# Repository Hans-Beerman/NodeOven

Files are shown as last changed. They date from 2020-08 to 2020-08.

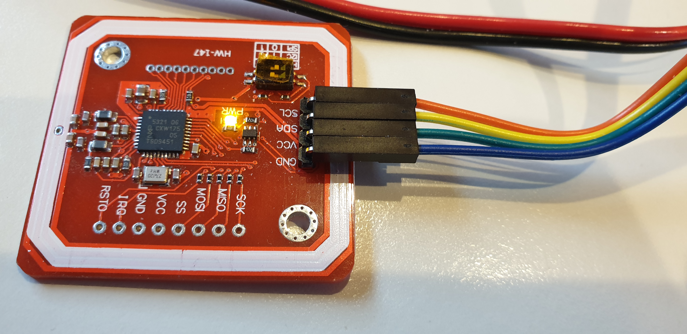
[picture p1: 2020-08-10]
Photos/20200808_105141.jpg

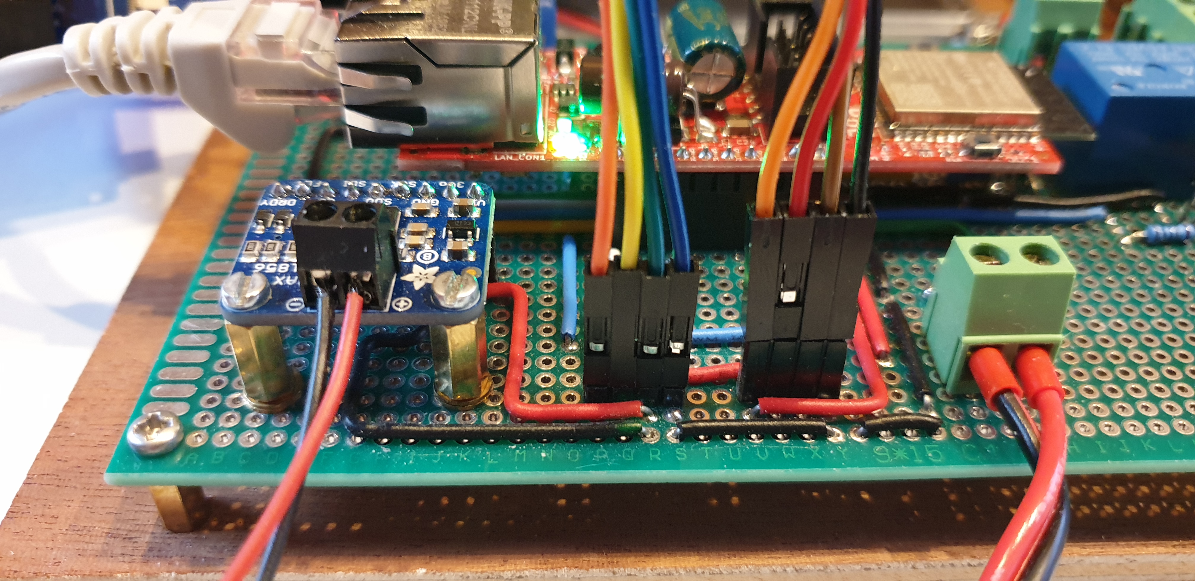
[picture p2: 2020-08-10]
Photos/20200808_105214.jpg

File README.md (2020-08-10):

**NodeOven**

NodeOven is a node, used at the MakerSpace Leiden, to control a Ceramic oven. This repository has the following subdirs:

- **Drawings:**

Schematic of the wiring between the different modules used

- **KiCad\_files:**

The design of the PCB for the Node/Controller. De PCB in this design is not meant to be used for a real PCB. It is used as guideline for a handmade PCB

- **Photos:**

Some photos of the Node made.

- **PlatformIO\_Files:**

The source code for the Node and the display used. For the development of this software PlatformIO is used, an Extension on Visual Studio Code.

For measuring the oven temperature different types of thermocouples can be used. The configuration of the correct one is done in:

/PlatformIO\_Files/NodeOven/platformio.ini

See for possible types to be used, the comment in this file for THERMOCOUPLE\_TYPE=

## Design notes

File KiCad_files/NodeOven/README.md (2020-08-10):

**NodeOven MakerSpace Leiden**

The NodeOven is used to control the ceramic oven of the MakerSpace in Leiden

This repository contains the schematic drawings, made in KiCad for this node.

The PCB in this design is not meant to be used for a real printed circuit board, but is added to be used as a guideline for making the print by hand on a prefab PCB for experimental use.

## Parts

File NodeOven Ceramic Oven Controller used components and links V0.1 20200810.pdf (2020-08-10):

RFID NFC Kit PN532 met S50 Kaart en S50 Key Tag: https://www.tinytronics.nl/shop/nl/communicatie/rfid/rfid-nfc-kit-pn532-met-s50-kaart-en-s50-keytag
https://github.com/elechouse/PN532http://www.elechouse.com/elechouse/index.php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
Of:
http://www.elechouse.com/elechouse/index.php?main_page=product_info&cPath=90_93&products_id=2242
Of:
https://www.elechouse.com/elechouse/index.php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

Adafruit Universele Thermokoppel Versterker MAX31856 Breakout: https://www.kiwi-electronics.nl/adafruit-universal-thermocouple-amplifier-max31856-breakouthttps://learn.adafruit.com/adafruit-max31856-thermocouple-amplifier/overvi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
https://github.com/adafruit/Adafruit_MAX31856

Solid state relais:
https://www.huimultd.com/MOTOR_SPEED_OR_DIRECTION_CONTROL_MODULE/MGR-3-M4825/

Wemos 2.4 inch TFT Shield voor D1 Mini - Met Touchscreen: https://www.tinytronics.nl/shop/nl/display/tft/wemos-2.4-inch-tft-shield-voor-d1-mini-mettouchscreen
https://docs.wemos.cc/en/latest/d1_mini_shiled/tft_2_4.htmlhttps://docs.wemos.cc/en/latest/_static/files/sch_tft2.4_v1.0.0.pdfhttps://docs.wemos.cc/en/latest/_static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 hield

RobotDyn D1 Mini Pro - ESP8266 - 4MB - CP2104: https://www.tinytronics.nl/shop/nl/arduino/wemos/robotdyn-d1-mini-pro-esp8266-4mb-cp2104https://robotdyn.com/wifi-d1-mini-esp8266-dev-board-usb-cp2104.htmlhttps://ro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
https://robotdyn.com/pub/media/images/pdf.png

ESP32-PoE:
https://www.olimex.com/Products/IoT/ESP32/ESP32-POE/open-source-hardwarehttps://github.com/OLIMEX/ESP32-POE/blob/master/HARDWARE/ESP32-PoE-hardware-revision-D/ESP32-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
https://www.olimex.com/Products/IoT/ESP32/ESP32-POE/resources/ESP32-POE-GPIO.png

Webserver:
https://lastminuteengineers.com/creating-esp32-web-server-arduino-ide/https://randomnerdtutorials.com/esp32-esp8266-input-data-html-form/https://circuits4you.com/201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

Ovenregeling:
https://create.arduino.cc/projecthub/arduinokiln/electric-kiln-controller-f5c633\https://art-et-ceramique.fr/regulateur-page-principalehttps://playground.arduino.cc/Code/PIDLibrary/

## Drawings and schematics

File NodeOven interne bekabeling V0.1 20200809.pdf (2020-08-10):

## SSR

20

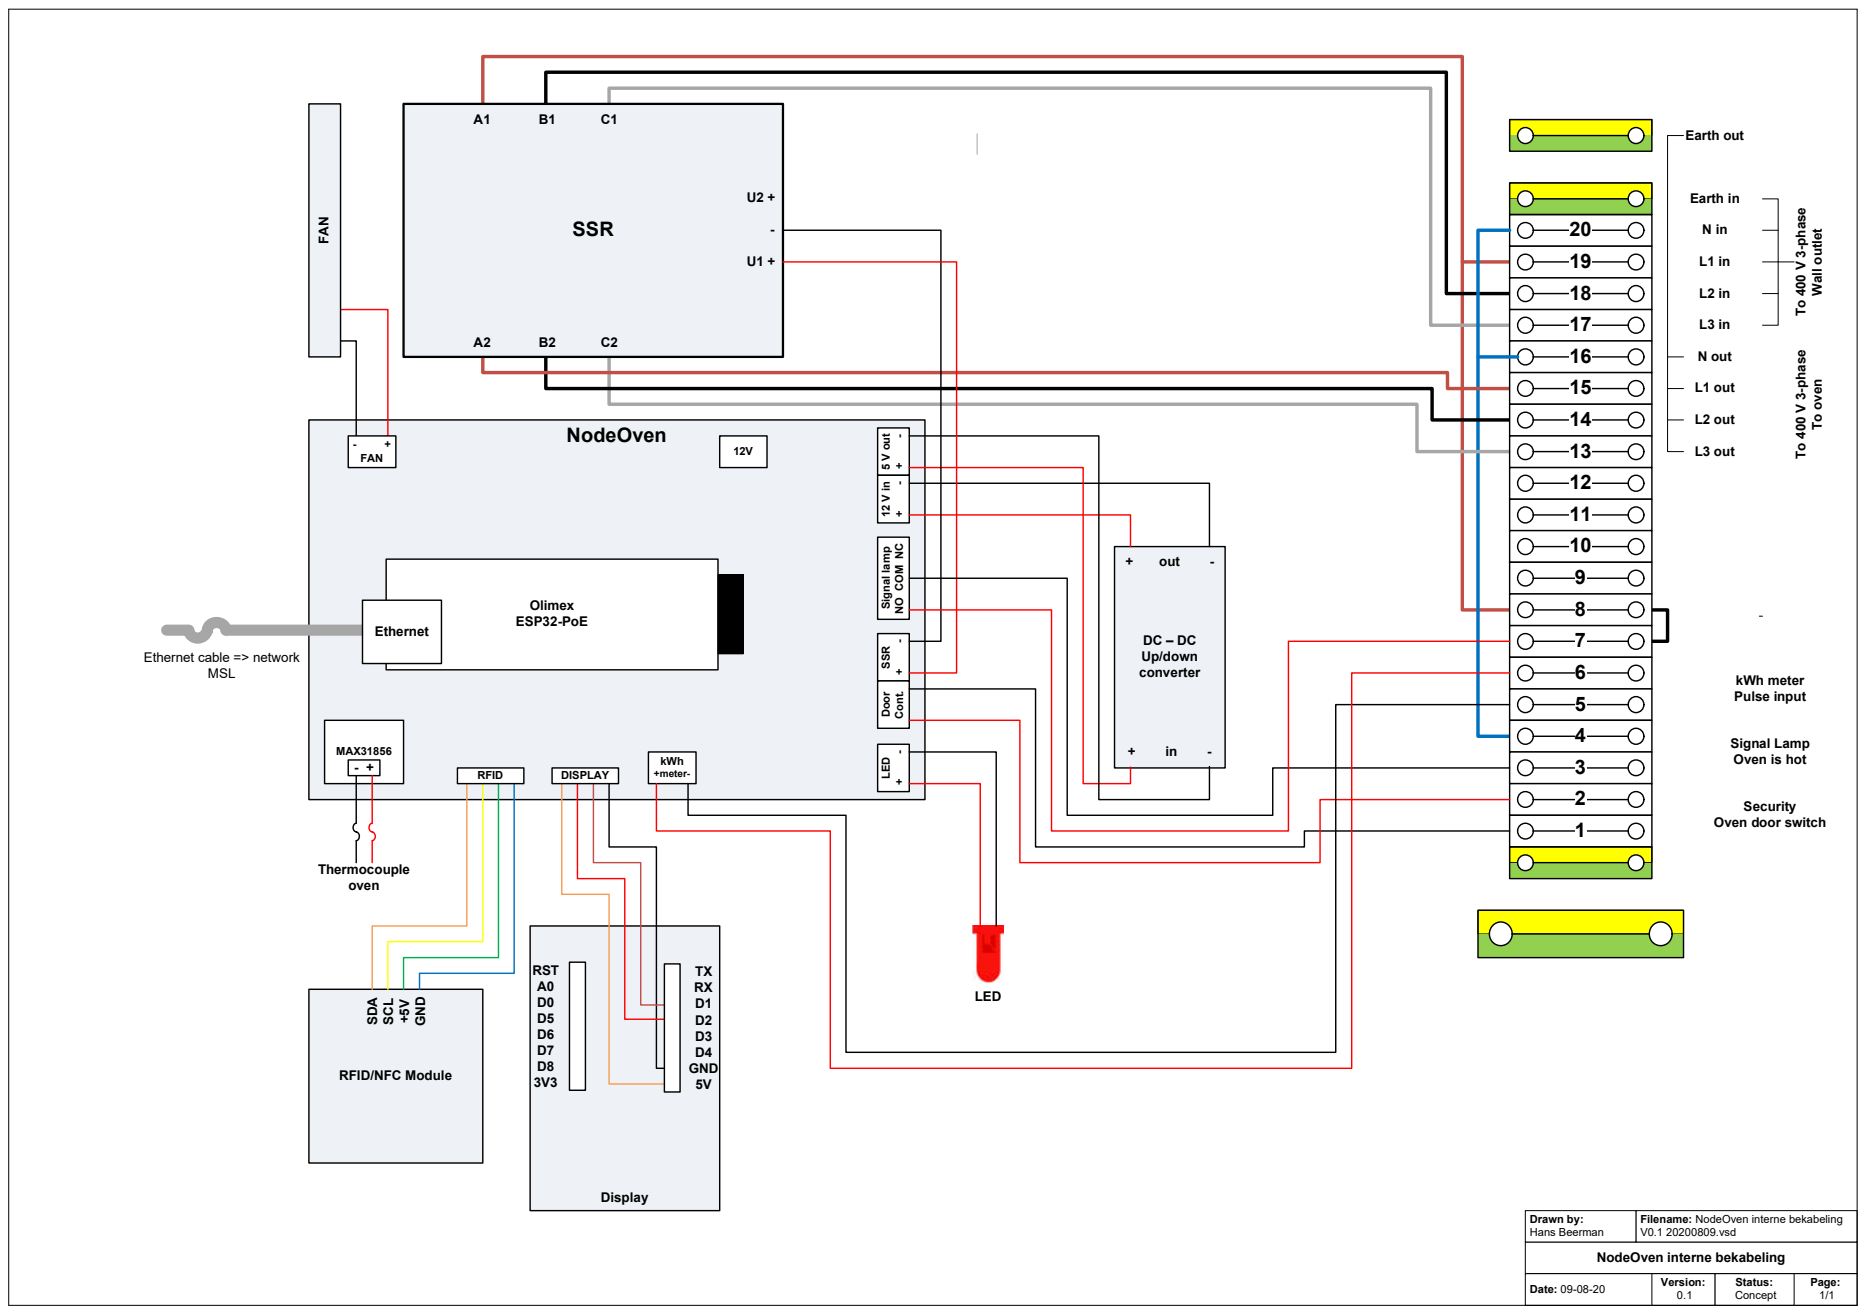
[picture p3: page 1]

Earth in

To 400 V 3-phase
N out L1 out L2 out L3 out

Filename: NodeOven interne bekabeling V0.1 20200809.vsd

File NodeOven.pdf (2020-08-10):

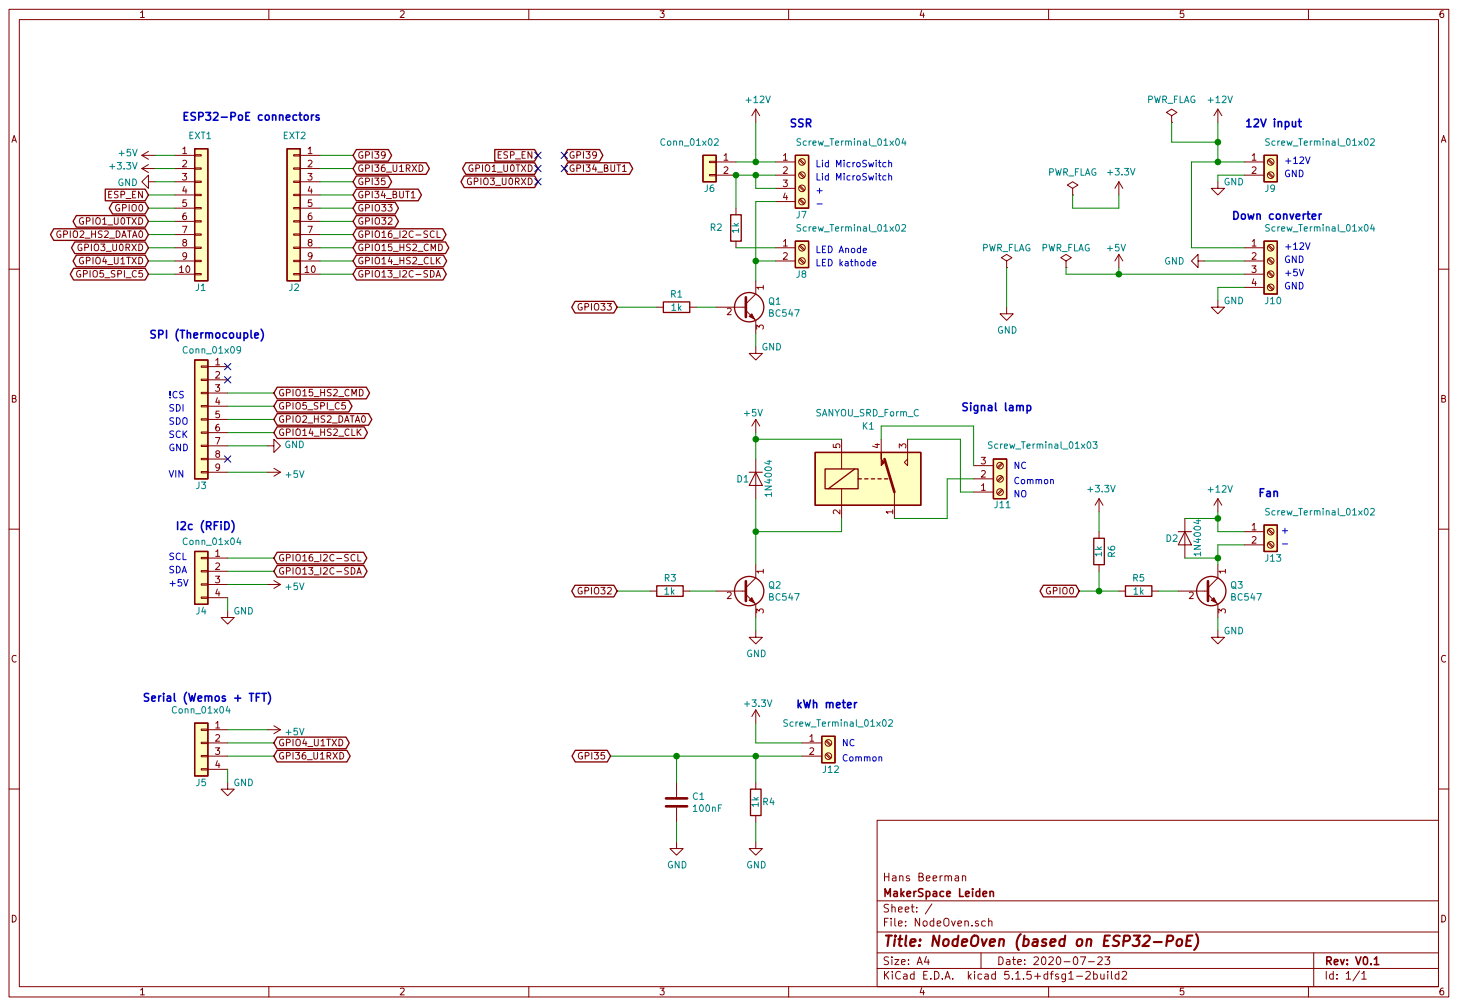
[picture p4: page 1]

Id: 1/1 Title: NodeOven (based on ESP32-PoE) File: NodeOven.sch Sheet: / MakerSpace Leiden Hans Beerman

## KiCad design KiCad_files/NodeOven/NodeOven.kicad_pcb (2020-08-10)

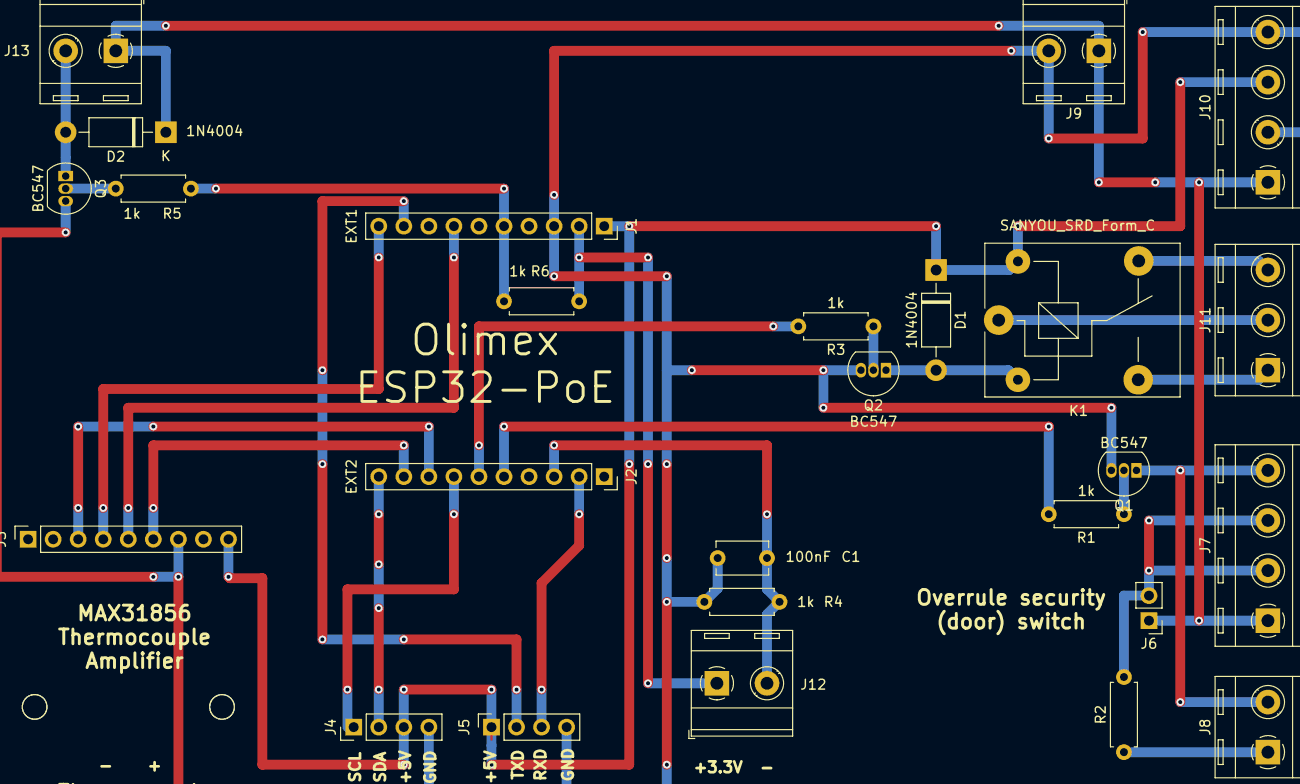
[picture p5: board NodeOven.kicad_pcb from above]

Board: 2 copper layers, 26 parts (0 on the bottom side), 27 nets.

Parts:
C1: 100nF; C_Disc_D5.1mm_W3.2mm_P5.00mm
D1, D2: 1N4004; D_DO-41_SOD81_P10.16mm_Horizontal
J1: EXT1; PinSocket_1x10_P2.54mm_Vertical
J2: EXT2; PinSocket_1x10_P2.54mm_Vertical
J3: Conn_01x09; PinSocket_1x09_P2.54mm_Vertical
J4: Conn_01x04; PinHeader_1x04_P2.54mm_Vertical
J5: Conn_01x04; PinSocket_1x04_P2.54mm_Vertical
J6: Conn_01x02; PinHeader_1x02_P2.54mm_Vertical
J7, J10: Screw_Terminal_01x04; TerminalBlock_RND_205-00289_1x04_P5.08mm_Horizontal
J8, J9, J12, J13: Screw_Terminal_01x02; TerminalBlock_RND_205-00287_1x02_P5.08mm_Horizontal
J11: Screw_Terminal_01x03; TerminalBlock_RND_205-00288_1x03_P5.08mm_Horizontal
K1: SANYOU_SRD_Form_C; Relay_SPDT_SANYOU_SRD_Series_Form_C
Q1, Q2, Q3: BC547; TO-92_Inline
R1, R2, R3, R4, R5, R6: 1k; R_Axial_DIN0207_L6.3mm_D2.5mm_P7.62mm_Horizontal

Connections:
+3V3: J1.2, J12.1, R6.2
+5V: D1.1, J1.1, J3.9, J4.3, J5.1, J10.3, K1.5
+12V: D2.1, J6.1, J7.1, J9.1, J10.1, J13.1
GND: C1.2, J1.3, J3.7, J4.4, J5.4, J9.2, J10.2, J10.4, Q1.3, Q2.3, Q3.3, R4.1
GPI35: C1.1, J2.3, J12.2, R4.2
GPI36_U1RXD: J2.2, J5.3
GPIO0: J1.5, R5.2, R6.1
GPIO2_HS2_DATA0: J1.7, J3.5
GPIO4_U1TXD: J1.9, J5.2
GPIO5_SPI_C5: J1.10, J3.4
GPIO13_I2C-SDA: J2.10, J4.2
GPIO14_HS2_CLK: J2.9, J3.6
GPIO15_HS2_CMD: J2.8, J3.3
GPIO16_I2C-SCL: J2.7, J4.1
GPIO32: J2.6, R3.2
GPIO33: J2.5, R1.2
unnamed: D1.2, K1.2, Q2.1
unnamed: D2.2, J13.2, Q3.1
unnamed: J6.2, J7.2, J7.3, R2.2
unnamed: J7.4, J8.2, Q1.1
unnamed: J8.1, R2.1
unnamed: J11.1, K1.3
unnamed: J11.2, K1.1
unnamed: J11.3, K1.4
unnamed: Q1.2, R1.1
unnamed: Q2.2, R3.1
unnamed: Q3.2, R5.1

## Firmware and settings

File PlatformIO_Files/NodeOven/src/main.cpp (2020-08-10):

/*
      Copyright 2015-2018 Dirk-Willem van Gulik <dirkx@webweaving.org>
      Copyright 2020      Hans Beerman <hans.beerman@xs4all.nl>
                          Stichting Makerspace Leiden, the Netherlands.

   Licensed under the Apache License, Version 2.0 (the "License");
   you may not use this file except in compliance with the License.
   You may obtain a copy of the License at

       http://www.apache.org/licenses/LICENSE-2.0

   Unless required by applicable law or agreed to in writing, software
   distributed under the License is distributed on an "AS IS" BASIS,
   WITHOUT WARRANTIES OR CONDITIONS OF ANY KIND, either express or implied.
   See the License for the specific language governing permissions and
   limitations under the License.
*/

#ifndef ESP32
#error "The MetalNode uses an ESP32 based board (Olimex ESP32-PoE)!"
#endif

// An Olimex ESP32-PoE is used (default is POESP board (Aart board))
#define ESP32_PoE


// for debugging
// see DEBUGIT flag in platformio.ini

// i2C params
#define RFID_SDA_PIN    (13)
#define RFID_SCL_PIN    (16)

#include <Arduino.h>
#include <PowerNodeV11.h>
#include <ACNode.h>
#include <RFID.h>   // NFC version
#include <SIG2.h>
#include <Cache.h>
#include <EEPROM.h>

#include ".passwd.h"
/* If using WiFi instead of a fixed ethernet connection, and/or OTA:

Add Passwd.h to the NodeOven/src directoy containing the following information

#pragma once

#define WIFI_NETWORK "YOUR_SSID"
#define WIFI_PASSWD "YOUR_PASSWD"

#define OTA_PASSWD "YOUR_OTA_PASSWD"
*/

#include "pid.h"


#define MACHINE "nodeoven"

#define SOLID_STATE_RELAIS_PIN  (33)
#define SIGNAL_LAMP_PIN         (32)
#define FAN_PIN                 (0)
#define KWH_METER_PIN           (35)

#define SERIAL_RX_PIN               36
#define SERIAL_TX_PIN               4

#define SERIAL_MAXLINELENGTH        128
#define SERIAL2_BAUDRATE            19200

#define DISPLAY_UPDATE_INTERVAL     1000 // in ms


// See https://mailman.makerspaceleiden.nl/mailman/private/deelnemers/2019-February/019837.html

// Introduced by alex - 2020-01-8

// Clear EEProm + Cache button
// Press BUT1 on Olimex ESP32 PoE module before (re)boot of node
// keep BUT1 pressed for at least 5 s
// After the release of BUT1 node will restart with empty EEProm and empty cache
#define CLEAR_EEPROM_AND_CACHE_BUTTON         (34)
#define CLEAR_EEPROM_AND_CACHE_BUTTON_PRESSED (LOW)
#define MAX_WAIT_TIME_BUTTON_PRESSED          (4000)  // in ms


#ifdef WIFI_NETWORK
ACNode node = ACNode(MACHINE, WIFI_NETWORK, WIFI_PASSWD);
#else
ACNode node = ACNode(MACHINE);
#endif

RFID reader = RFID(false); // don't use tags already stored in cache, to see in the server who has used the oven

MqttLogStream mqttlogStream = MqttLogStream();
TelnetSerialStream telnetSerialStream = TelnetSerialStream();

// Use software SPI: CS, DI, DO, CLK
Adafruit_MAX31856 thermo = Adafruit_MAX31856(15, 5, 2, 14);


#ifdef OTA_PASSWD
OTA ota = OTA(OTA_PASSWD);
#endif

// LED aartLed = LED(SYSTEM_LED);    // defaults to the aartLed - otherwise specify a GPIO.

typedef enum {
  BOOTING, OUTOFORDER,      // device not functional.
  REBOOT,                   // forcefull reboot
  TRANSIENTERROR,           // hopefully goes away level error
  NOCONN,                   // sort of fairly hopless (though we can cache RFIDs!)
  WAITINGFORCARD,           // waiting for card.
  CHECKINGCARD,
  CLEARSTATUS,
  APPROVED,
  REJECTED,
  OVENON,
  OVENOFF,
} machinestates_t;


#define NEVER (0)

struct {
  const char * label;                   // name of this state
  LED::led_state_t ledState;            // flashing pattern for the aartLED. Zie ook https://wiki.makerspaceleiden.nl/mediawiki/index.php/Powernode_1.1.
  time_t maxTimeInMilliSeconds;         // how long we can stay in this state before we timeout.
  machinestates_t failStateOnTimeout;   // what state we transition to on timeout.
  unsigned long timeInState;
  unsigned long timeoutTransitions;
  unsigned long autoReportCycle;
} state[OVENOFF + 1] =
{
  { "Booting",                LED::LED_ERROR,                   120 * 1000, REBOOT,         0 },
  { "Out of order",           LED::LED_ERROR,                   120 * 1000, REBOOT,         5 * 60 * 1000 },
  { "Rebooting",              LED::LED_ERROR,                   120 * 1000, REBOOT,         0 },
  { "Transient Error",        LED::LED_ERROR,                     5 * 1000, WAITINGFORCARD, 5 * 60 * 1000 },
  { "No network",             LED::LED_FLASH,                        NEVER, NOCONN,         0 },
  { "Waiting for card",       LED::LED_IDLE,                         NEVER, WAITINGFORCARD, 0 },
  { "Checking card",          LED::LED_PENDING,                   5 * 1000, WAITINGFORCARD, 0 },
  { "Clear status",           LED::LED_PENDING,                      NEVER, WAITINGFORCARD, 0 },
  { "Approved card",          LED::LED_PENDING,                  60 * 1000, CLEARSTATUS,    0 },
  { "Rejected",               LED::LED_ERROR,                     5 * 1000, CLEARSTATUS,    0 },
  { "Device(s) switched on",  LED::LED_ON,  MAX_OVEN_ON_TIME * 3600 * 1000, OVENOFF,        0 },
  { "Switch oven off",        LED::LED_ON,                           NEVER, WAITINGFORCARD, 0 },
};

enum messID {
  e_Beat = 1,
  e_Prev,
  e_Next,
  e_On,
  e_Off
};

enum displayMessageID {
	e_BeatAnswer = 1,
	e_CurrentSchedule,
	e_ScheduleName,
	e_CurrentSegment,
	e_Mode,
	e_Goal,
	e_TimeLeft,
	e_Empty,
	e_IsOn,
	e_IsOff,
	e_Fault,
	e_Solved,
	e_OvenTemp,
	e_Authenticate,
	e_ClearMessage,
	e_Status
};

unsigned long laststatechange = 0, lastReport = 0;
static machinestates_t laststate = OUTOFORDER;
machinestates_t machinestate = BOOTING;

// to handle onconnect only once (only after reboot)
static bool firstOnConnectTime = true;

PIDController * _OvenController;

char reportStr[128];

ESP32WebServer myWebServer(80);

unsigned long wattPulses = 0;
bool kWhPinIsHigh = false;
unsigned long startPinChange = 0;

char messageReceived[SERIAL_MAXLINELENGTH];

bool firstTimeSerialBeatReceived = true;

char tmpStr[255];

unsigned long displayUpdateStartTime = 0;

int prevSchedule = -1;
int prevSegment = -1;
bool clearMessageSent = false;

bool thermoCoupleFault = false;

void updateDisplayTop() {
  String tmpStr;
  char resultStr[SERIAL_MAXLINELENGTH];

  if (prevSchedule != _OvenController->getSelectedSchedule()) {
    prevSchedule = _OvenController->getSelectedSchedule();
    prevSegment = -1;
    sprintf(resultStr, "%d:%d", e_CurrentSchedule, _OvenController->getSelectedSchedule());
    Serial2.println(resultStr);
    tmpStr = _OvenController->getScheduleName();
    sprintf(resultStr, "%d:%s", e_ScheduleName, tmpStr.c_str());
    Serial2.println(resultStr);
    if (_OvenController->getScheduleIsEmpty()) {
      sprintf(resultStr, "%d", e_Empty);
      Serial2.println(resultStr);
    } else {
      sprintf(resultStr, "%d", e_ClearMessage);
      Serial2.println(resultStr);
    }
  }
}

void updateDisplayBottom() {
  String tmpStr;
  char resultStr[SERIAL_MAXLINELENGTH];

  if ((machinestate == OVENON) || _OvenController->ovenIsSwitchedOn()) {
    if (prevSegment != _OvenController->getCurrentSegment()) {
      prevSegment = _OvenController->getCurrentSegment();
      sprintf(resultStr, "%d:%d", e_CurrentSegment, _OvenController->getCurrentSegment());
      Serial2.println(resultStr);
      sprintf(resultStr, "%d:%s", e_Mode, _OvenController->getCurrentMode().c_str());
      Serial2.println(resultStr);
      sprintf(resultStr, "%d:%d", e_Goal, (int)_OvenController->getCurrentGoal());
      Serial2.println(resultStr);
      clearMessageSent = false;
    }
    sprintf(resultStr, "%d:%lu", e_TimeLeft, _OvenController->getTimeLeft());
    Serial2.println(resultStr);
  } else {
    if (!clearMessageSent) {
      sprintf(resultStr, "%d", e_ClearMessage);
      Serial2.println(resultStr);
      clearMessageSent = true;
    }
  }
}

void decodeMessageReceived(int messageID) {
  //String tmpStr;
  char resultStr[SERIAL_MAXLINELENGTH];
 

  switch (messageID) {
  case e_Beat:
    // BEAT received, answer with BEAT
    sprintf(resultStr, "%d", e_BeatAnswer);
    Serial2.println(resultStr);
    if (firstTimeSerialBeatReceived) {
      firstTimeSerialBeatReceived = false;
      updateDisplayTop();
    }
    break;

  case e_Prev:
    // Select previous schedule
    // Check if oven is switched off
    if ((machinestate == OVENON) || _OvenController->ovenIsSwitchedOn()) {
      // skip message
    } else {
      _OvenController->selectSchedule(false);
      updateDisplayTop();
    }
    break;

  case e_Next:
    // Select next schedule
    //Check if oven is switched off
    if ((machinestate == OVENON) || _OvenController->ovenIsSwitchedOn()) {
      // skip message
    } else {
      _OvenController->selectSchedule(true);
      updateDisplayTop();
    }
    break;
      
  case e_On:
    // Switch oven on (if needed/possible)
    // Check if oven is already on
    if ((machinestate == OVENON) || _OvenController->ovenIsSwitchedOn()) {
      // skip request, oven is already on
      return;
    }
 
    // Check if schedule is empty
    if (_OvenController->getScheduleIsEmpty()) {
      sprintf(resultStr, "%d", e_Empty);
      Serial2.println(resultStr);
      return;
    }
 
    // Check if user is approved
    if (machinestate != APPROVED) {
      sprintf(resultStr, "%d", e_Authenticate);
      Serial2.println(resultStr);

      return;
    }

    // Switch oven on
    _OvenController->switchOvenOn();
    sprintf(resultStr, "%d", e_IsOn);
    Serial2.println(resultStr);
    sprintf(resultStr, "%d:0", e_Status); // clear status
    Serial2.println(resultStr);
    machinestate = OVENON;
    prevSegment = -1;
    updateDisplayBottom();
    break;

  case e_Off:
    // switch oven off
    _OvenController->switchOvenOff();
    sprintf(resultStr, "%d", e_IsOff);
    Serial2.println(resultStr);
    machinestate = WAITINGFORCARD;
    sprintf(resultStr, "%d:0", e_Status); // clear status
    Serial2.println(resultStr);
    clearMessageSent = false;
    updateDisplayBottom();
    break;
  }
}

void readSerial2()
{
  if (Serial2.available()) {
    //memset(messageReceived, 0, sizeof(messageReceived));

    while (Serial2.available())
    {
      int len = Serial2.readBytesUntil('\n', messageReceived, SERIAL_MAXLINELENGTH - 1);
      messageReceived[len] = 0;
#ifdef DEBUGIT      
      // Serial.printf("Message received: %s\n\r", messageReceived);
#endif      

      int messageId = atoi(messageReceived);
      decodeMessageReceived(messageId);
    }
  }
}

void displayLoop() {
  if ((millis() - displayUpdateStartTime) > DISPLAY_UPDATE_INTERVAL) {
    displayUpdateStartTime = millis();
    if ((machinestate == OVENON) || _OvenController->ovenIsSwitchedOn()) {
      updateDisplayBottom();
    } else {
      updateDisplayTop();
    }
    double currentOvenTemp = _OvenController->getThermoCoupleTemp();
    if ((currentOvenTemp > -300) && !_OvenController->getTempFault()) {
      sprintf(tmpStr, "%d:%d", e_OvenTemp, (int)currentOvenTemp);
      Serial2.println(tmpStr);
      if (thermoCoupleFault) {
        sprintf(tmpStr, "%d", e_Solved);
        Serial2.println(tmpStr);
        thermoCoupleFault = false;
      }
    } else {
      if (_OvenController->getTempFault()) {
        if (!thermoCoupleFault) {
          thermoCoupleFault = true;
          sprintf(tmpStr, "%d", e_Fault);
          Serial2.println(tmpStr);
        }
      }
    }
  }
}

void countkWhPulses() {
  int currentPinValue = 0;
  currentPinValue = digitalRead(KWH_METER_PIN);
  if (( currentPinValue == HIGH) && !kWhPinIsHigh && (millis() - startPinChange) > 50) {
    startPinChange = millis();
    wattPulses++;
    kWhPinIsHigh = true;
  } else {
    if ((currentPinValue == LOW) && kWhPinIsHigh && (millis() - startPinChange) > 50) {
      startPinChange = millis();
      kWhPinIsHigh = false;
    }
  }
}

void checkClearEEPromAndCacheButtonPressed(void) {
  unsigned long ButtonPressedTime;
  unsigned long currentSecs;
  unsigned long prevSecs;
  bool firstTime = true;

  // check CLEAR_EEPROM_AND_CACHE_BUTTON pressed
  pinMode(CLEAR_EEPROM_AND_CACHE_BUTTON, INPUT);
  // check if button is pressed for at least 3 s
  Log.println("Checking if the button is pressed for clearing EEProm and cache");
  ButtonPressedTime = millis();  
  prevSecs = MAX_WAIT_TIME_BUTTON_PRESSED / 1000;
  Log.print(prevSecs);
  Log.print(" s");
  while (digitalRead(CLEAR_EEPROM_AND_CACHE_BUTTON) == CLEAR_EEPROM_AND_CACHE_BUTTON_PRESSED) {
    if ((millis() - ButtonPressedTime) >= MAX_WAIT_TIME_BUTTON_PRESSED) {
      if (firstTime == true) {
        Log.print("\rPlease release button");
        firstTime = false;
      }
    } else {
      currentSecs = (MAX_WAIT_TIME_BUTTON_PRESSED - millis()) / 1000;
      if ((currentSecs != prevSecs) && (currentSecs >= 0)) {
        Log.print("\r");
        Log.print(currentSecs);
        Log.print(" s");
        prevSecs = currentSecs;
      }
    }
  }
  if (millis() - ButtonPressedTime >= MAX_WAIT_TIME_BUTTON_PRESSED) {
    Log.print("\rButton for clearing EEProm and cache was pressed for more than ");
    Log.print(MAX_WAIT_TIME_BUTTON_PRESSED / 1000);
    Log.println(" s, EEProm and Cache will be cleared!");
    // Clear EEPROM
    EEPROM.begin(1024);
    wipe_eeprom();
    Log.println("EEProm cleared!");
    // Clear cache
    prepareCache(true);
    Log.println("Cache cleared!");
    // wait until button is released, than reboot
    while (digitalRead(CLEAR_EEPROM_AND_CACHE_BUTTON) == CLEAR_EEPROM_AND_CACHE_BUTTON_PRESSED) {
      // do nothing here
    }
    Log.println("Node will be restarted");
    // restart node
    ESP.restart();
  } else {
    Log.println("\rButton was not (or not long enough) pressed to clear EEProm and cache");
  }
}


int inputIsHigh = 0;

void handleNotFound() {
  myWebServer.send(404, "text/plain", "404: Not found"); // Send HTTP status 404 (Not Found) when there's no handler for the URI in the request
}


void setup() {
  Serial.begin(115200);
  Serial.println("\n\n\n");
  Serial.println("Booted: " __FILE__ " " __DATE__ " " __TIME__ );

  Serial2.begin(SERIAL2_BAUDRATE, SERIAL_8N1, SERIAL_RX_PIN, SERIAL_TX_PIN);
  Serial2.setRxBufferSize(256);
  Serial2.flush();

  sprintf(tmpStr, "%d:1", e_Status); // Please wait, controller is starting
  Serial2.println(tmpStr);

  pinMode(KWH_METER_PIN, INPUT);

  checkClearEEPromAndCacheButtonPressed();

  _OvenController = new PIDController();
  _OvenController->begin(SOLID_STATE_RELAIS_PIN, FAN_PIN, SIGNAL_LAMP_PIN);

  node.set_mqtt_prefix("ac");
  node.set_master("master");

  node.onConnect([]() {
    Log.println("Connected");
    if (firstOnConnectTime == true) {
      _OvenController->setUserIsApproved(false);
      firstOnConnectTime = false;
      machinestate = WAITINGFORCARD;
    }
  });
  node.onDisconnect([]() {
    Log.println("Disconnected");
//    machinestate = NOCONN;
  });
  node.onError([](acnode_error_t err) {
    Log.printf("Error %d\n", err);
    _OvenController->setUserIsApproved(false);
    machinestate = WAITINGFORCARD;
  });
  node.onApproval([](const char * machine) {
    char resultStr2[SERIAL_MAXLINELENGTH];
    Debug.print("Got approve for machine: ");
    Debug.println(machine);
    if (machinestate == WAITINGFORCARD) {
      _OvenController->setUserIsApproved(true);
      sprintf(resultStr2, "%d:2", e_Status); // User authenticated
      Serial2.println(resultStr2);

      sprintf(resultStr2, "%d", e_ClearMessage);
      Serial2.println(resultStr2);

      machinestate = APPROVED;
      Log.println("User is approved and is now allowed to switch the oven on");
    }
  });
  node.onDenied([](const char * machine) {
    char resultStr3[SERIAL_MAXLINELENGTH];
    Debug.println("Got denied");
    if (machinestate > REJECTED) {
      Debug.println("Denied ingnored, oven is already in use");
    } else {
      machinestate = REJECTED;
      _OvenController->setUserIsApproved(false);
      sprintf(resultStr3, "%d:3", e_Status);  // User denied
      Serial2.println(resultStr3);
    }
  });

  node.set_report_period(20 * 1000);
  node.onReport([](JsonObject  & report) {
    report["state"] = state[machinestate].label;

    if (_OvenController->getAllowPidControllerIsOn()) {
      report["ovencontroller"] = "enabled";
    } else {
      report["ovencontroller"] = "disabled";
    }

    if (_OvenController->getSSRIsOn()) {
      report["Solid State Relais"] = "switched on";
    } else {
      report["Solid State Relais"] = "switched off";
    }

    _OvenController->measureOvenTemps();
    if (_OvenController->getTempFault()) {
      report["Thermocouple"] = "error detected";
    } else {
      report["Thermocouple"] = "working OK";
      if (_OvenController->getValidTemps()) {
        sprintf(reportStr, "Internal temperature node = %6.1f degrees Celcius", _OvenController->getInternalTemp());
        report["Thermocouple"] = reportStr;
        sprintf(reportStr, "Oven temperature = %6.1f degrees Celcius", _OvenController->getThermoCoupleTemp());
        report["Thermocouple"] = reportStr;
      } else {
        report["Thermocouple"] = "No valid temperature readings available";
      }
    }

#ifdef OTA_PASSWD
    report["ota"] = true;
#else
    report["ota"] = false;
#endif
  });

  reader.onSwipe([](const char * tag) -> ACBase::cmd_result_t {

    // avoid swithing messing with the swipe process
    if (machinestate > CHECKINGCARD) {
      Debug.printf("Ignoring a normal swipe - as we're still in some open process.");
      return ACBase::CMD_CLAIMED;
    }

    // We'r declining so that the core library handle sending
    // an approval request, keep state, and so on.
    //
    Debug.printf("Detected a normal swipe.\n");
  //  buzz = CHECK;
    return ACBase::CMD_DECLINE;
  });


  // This reports things such as FW version of the card; which can 'wedge' it. So we
  // disable it unless we absolutely positively need that information.
  //
  reader.set_debug(false);
  node.addHandler(&reader);
 
#ifdef OTA_PASSWD
  node.addHandler(&ota);
#endif

  Log.addPrintStream(std::make_shared<MqttLogStream>(mqttlogStream));

  auto t = std::make_shared<TelnetSerialStream>(telnetSerialStream);
  Log.addPrintStream(t);
  Debug.addPrintStream(t);

  // node.set_debug(true);
  // node.set_debugAlive(true);

// if Olimex ESP32-PoE board is used
#ifdef ESP32_PoE  
  node.begin(BOARD_OLIMEX);
#endif
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
void loop() {
  node.loop();

  readSerial2();

  displayLoop();

  myWebServer.handleClient(); 
   
  _OvenController->PIDloop();
  // test_Loop_PID();

  _OvenController->scheduleLoop();
  
  _OvenController->checkTemps();

  countkWhPulses();

  // test_Loop();

  if (laststate != machinestate) {
    Debug.printf("Changed from state <%s> to state <%s>\n",
                 state[laststate].label, state[machinestate].label);

    state[laststate].timeInState += (millis() - laststatechange) / 1000;
    laststate = machinestate;
    laststatechange = millis();
    return;
  }

  if (state[machinestate].maxTimeInMilliSeconds != NEVER &&
      ((millis() - laststatechange) > state[machinestate].maxTimeInMilliSeconds))
  {
    state[machinestate].timeoutTransitions++;

    laststate = machinestate;
    machinestate = state[machinestate].failStateOnTimeout;

    Log.printf("Time-out; transition from <%s> to <%s>\n",
               state[laststate].label, state[machinestate].label);
    return;
  };

  if (state[machinestate].autoReportCycle && \
      (millis() - laststatechange) > state[machinestate].autoReportCycle && \
      (millis() - lastReport) > state[machinestate].autoReportCycle)
  {
    Log.printf("State: %s now for %lu seconds", state[laststate].label, (millis() - laststatechange) / 1000);
    lastReport = millis();
  };

  // aartLed.set(state[machinestate].ledState);

  switch (machinestate) {
    case REBOOT:
      node.delayedReboot();
      break;

    case WAITINGFORCARD:
    case CHECKINGCARD:
      break;
    case CLEARSTATUS:
      sprintf(tmpStr, "%d:0", e_Status); // Clear status
      Serial2.println(tmpStr);
      sprintf(tmpStr, "%d", e_ClearMessage);
      Serial2.println(tmpStr);
      machinestate = WAITINGFORCARD;
      break;
    case REJECTED:
      break;
    case APPROVED:
      if (_OvenController->ovenIsSwitchedOn()) {
        _OvenController->setUserIsApproved(false);
        sprintf(tmpStr, "%d:0", e_Status); // Clear status
        Serial2.println(tmpStr);
        machinestate = OVENON;
        sprintf(tmpStr, "%d", e_IsOn);
        Serial2.println(tmpStr);
        updateDisplayBottom();
        wattPulses = 0;
      }
      break;
    case OVENON:
      // wait until schedule is ready
      if (_OvenController->ovenIsSwitchedOff()) {
        _OvenController->setUserIsApproved(false);
        machinestate = WAITINGFORCARD;
        sprintf(tmpStr, "%d", e_IsOff);
        Serial2.println(tmpStr);
        clearMessageSent = false;
        updateDisplayBottom();
        Log.printf("Count watt pulses = %lu\n\r", wattPulses);
        Log.printf("Oven schedule ready, used energy = %7.3f kWh\n\r", (double)wattPulses / 1000);
      }
      break;
    case OVENOFF:
      _OvenController->switchOvenOff();
      _OvenController->setUserIsApproved(false);
      Log.printf("Count watt pulses = %lu\n\r", wattPulses);
      Log.printf("Oven schedule ready, used energy = %7.3f kWh\n\r", (double)wattPulses / 1000);
      sprintf(tmpStr, "%d", e_IsOff);
      Serial2.println(tmpStr);
      clearMessageSent = false;
      updateDisplayBottom();
      machinestate = WAITINGFORCARD;
      break;
    case BOOTING:
    case OUTOFORDER:
    case TRANSIENTERROR:
    case NOCONN:
      break;
  };
}

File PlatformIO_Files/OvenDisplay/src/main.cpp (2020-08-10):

#include <Arduino.h>
#include <EEPROM.h>
#include <ESP8266WiFi.h>
#include <WiFiManager.h>
#include <ESP8266mDNS.h>
#include <ArduinoOTA.h>

// * Include settings
#include "settingsMainOven.h"

// * Include other modules
#include "OvenDisplay.h"

// * Initiate WIFI client
// WiFiClient espClient;

// * Gets called when WiFiManager enters configuration mode
void configModeCallback(WiFiManager *myWiFiManager)
{
  Serial.println(F("Entered config mode"));
  Serial.println(WiFi.softAPIP());

  // * If you used auto generated SSID, print it
  Serial.println(myWiFiManager->getConfigPortalSSID());
}

// **********************************
// * EEPROM helpers                 *
// **********************************

String read_eeprom(int offset, int len)
{
  Serial.print(F("read_eeprom()"));

  String res = "";
  for (int i = 0; i < len; ++i)
  {
    res += char(EEPROM.read(i + offset));
  }
  return res;
}

void write_eeprom(int offset, int len, String value)
{
  Serial.println(F("write_eeprom()"));
  for (int i = 0; i < len; ++i)
  {
    if ((unsigned)i < value.length())
    {
      EEPROM.write(i + offset, value[i]);
    }
    else
    {
      EEPROM.write(i + offset, 0);
    }
  }
}

// ******************************************
// * Callback for saving WIFI config        *
// ******************************************

bool shouldSaveConfig = false;

// * Callback notifying us of the need to save config
void save_wifi_config_callback ()
{
  Serial.println(F("Should save config"));
  shouldSaveConfig = true;
}

// **********************************
// * Setup OTA                      *
// **********************************

void setup_ota()
{
  Serial.println(F("Arduino OTA activated."));

  // * Port defaults to 8266
  ArduinoOTA.setPort(8266);

  // * Set hostname for OTA
  ArduinoOTA.setHostname(HOSTNAME);
  ArduinoOTA.setPassword(OTA_PASSWORD);

  ArduinoOTA.onStart([]()
  {
    Serial.println(F("Arduino OTA: Start"));
  });

  ArduinoOTA.onEnd([]()
  {
    Serial.println(F("Arduino OTA: End (Running reboot)"));
  });

  ArduinoOTA.onProgress([](unsigned int progress, unsigned int total)
  {
    Serial.printf("Arduino OTA Progress: %u%%\r", (progress / (total / 100)));
  });

  ArduinoOTA.onError([](ota_error_t error)
  {
    Serial.printf("Arduino OTA Error[%u]: ", error);
    if (error == OTA_AUTH_ERROR)
    {
      Serial.println(F("Arduino OTA: Auth Failed"));
    }
    else if (error == OTA_BEGIN_ERROR)
    {
      Serial.println(F("Arduino OTA: Begin Failed"));
    }
    else if (error == OTA_CONNECT_ERROR)
    {
      Serial.println(F("Arduino OTA: Connect Failed"));
    }
    else if (error == OTA_RECEIVE_ERROR)
    {
      Serial.println(F("Arduino OTA: Receive Failed"));
    }
    else if (error == OTA_END_ERROR)
    {
      Serial.println(F("Arduino OTA: End Failed"));
    }
  });

  ArduinoOTA.begin();
  Serial.println(F("Arduino OTA init is finished"));
}

// **********************************
// * Setup MDNS discovery service   *
// **********************************

void setup_mdns()
{
  Serial.println(F("Starting MDNS responder service"));

  bool mdns_result = MDNS.begin(HOSTNAME);
  if (mdns_result)
  {
    MDNS.addService("http", "tcp", 80);
  }
}

// **********************************
// * Setup Main                     *
// **********************************

void setup() {
  // put your setup code here, to run once:

  // * Configure Serial and EEPROM
  Serial.begin(BAUD_RATE);
  EEPROM.begin(512);
    
  // * WiFiManager local initialization. Once its business is done, there is no need to keep it around
  WiFiManager wifiManager;

  // * Reset settings - uncomment for testing
  // wifiManager.resetSettings();

  // * Set callback that gets called when connecting to previous WiFi fails, and enters Access Point mode
  wifiManager.setAPCallback(configModeCallback);

  // * Set timeout
  wifiManager.setConfigPortalTimeout(WIFI_TIMEOUT);

  // * Set save config callback
  wifiManager.setSaveConfigCallback(save_wifi_config_callback);

  // * Fetches SSID and pass and tries to connect
  // * Reset when no connection after 10 seconds
  if (!wifiManager.autoConnect(WIFI_NETWORK, WIFI_PASSWD))
  {
    Serial.println(F("Failed to connect to WIFI and hit timeout"));

   // * Reset and try again, or maybe put it to deep sleep
    ESP.reset();
    delay(WIFI_TIMEOUT);
  }

  // * Save the custom parameters to FS
  if (shouldSaveConfig)
  {
    Serial.println(F("Saving WiFiManager config"));

    write_eeprom(134, 1, "1");        // * 134 --> always "1"
    EEPROM.commit();
  }

  // * If you get here you have connected to the WiFi
  Serial.println(F("Connected to WIFI..."));

  // * Configure OTA
  setup_ota();

  // * Startup MDNS Service
  setup_mdns();

  IPAddress ip;

  ip = WiFi.localIP();
  Serial.print("IP Address = ");
  Serial.println(ip);

  beginDisplay();
}

// **********************************
// * Loop                           *
// **********************************

void loop() {
  // put your main code here, to run repeatedly:
  ArduinoOTA.handle();
  read_softw_serial();
  loopDisplay();


}

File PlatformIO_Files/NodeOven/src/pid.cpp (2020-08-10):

/*
      Copyright 2020      Hans Beerman <hans.beerman@xs4all.nl>
                          Stichting Makerspace Leiden, the Netherlands.

   Licensed under the Apache License, Version 2.0 (the "License");
   you may not use this file except in compliance with the License.
   You may obtain a copy of the License at

       http://www.apache.org/licenses/LICENSE-2.0

   Unless required by applicable law or agreed to in writing, software
   distributed under the License is distributed on an "AS IS" BASIS,
   WITHOUT WARRANTIES OR CONDITIONS OF ANY KIND, either express or implied.
   See the License for the specific language governing permissions and
   limitations under the License.
*/

#include "pid.h"

#include <Arduino.h>
#include <ACNode.h>

PIDController::PIDController() {
    return;
}

void PIDController::begin(int SSRPin, int FANPin, int LAMPPin, int OutputPowerRange, double initialOvenTemp) {

    SSRPinUsed = SSRPin;
    SSRPowerRange = OutputPowerRange;
    FANPinUsed = FANPin;
    LAMPPinUsed = LAMPPin;

    pinMode(SSRPinUsed, OUTPUT);
    digitalWrite(SSRPinUsed, LOW);

    pinMode(FANPinUsed, OUTPUT);
    digitalWrite(FANPinUsed, LOW);

    pinMode(LAMPPinUsed, OUTPUT);
    digitalWrite(LAMPPinUsed, LOW);

    allowPIDControllerIsOn = false;

    _thermoCouple = new Adafruit_MAX31856(SPI_CS, SPI_DI, SPI_DO, SPI_CLK);

    if (!_thermoCouple->begin()) {
        Log.println("Could not initialize thermocouple.");
    } else {
        Log.println("Thermo couple init OK!");
    }
    
    _thermoCouple->setThermocoupleType(THERMOCOUPLE_TYPE);

    Log.print("Thermocouple type: ");
    switch (_thermoCouple->getThermocoupleType() ) {
        case MAX31856_TCTYPE_B: 
            Log.println("B Type"); 
            break;
        case MAX31856_TCTYPE_E: 
            Log.println("E Type"); 
            break;
        case MAX31856_TCTYPE_J: 
            Log.println("J Type"); 
            break;
        case MAX31856_TCTYPE_K: 
            Log.println("K Type"); 
            break;
        case MAX31856_TCTYPE_N: 
            Log.println("N Type"); 
            break;
        case MAX31856_TCTYPE_R: 
            Log.println("R Type"); 
            break;
        case MAX31856_TCTYPE_S: 
            Log.println("S Type"); 
            break;
        case MAX31856_TCTYPE_T: 
            Log.println("T Type"); 
            break;
        case MAX31856_VMODE_G8: 
            Log.println("Voltage x8 Gain mode"); 
            break;
        case MAX31856_VMODE_G32: 
            Log.println("Voltage x8 Gain mode"); 
            break;
        default: 
            Log.println("Unknown"); 
            break;
        checkTempStartTime = millis();
    }

    initSchedules();
    loadAllSchedules();

    _SSRPID = new PID(&currentOvenTemp, &outputPower, &setPointTemp, 2, 5, 1, DIRECT);

    pulseStartTime = millis();

    setPointTemp = initialOvenTemp;

    _SSRPID->SetOutputLimits(0, (double) OutputPowerRange);

    _SSRPID->SetMode(AUTOMATIC);

    _SSRPID->SetSampleTime(1000);

    switchOvenOff();
}

void PIDController::PIDloop() {
    if (allowPIDControllerIsOn) {
        if (getNewTemp && ((millis() - startSampleTime) > PID_SAMPLE_TIME)) {
            startSampleTime = millis();
            currentOvenTemp = measureOvenTemps();
            getNewTemp = false;
        } else {
            currentOvenTemp = currentThermoCoupleTemp;
        }

        if (currentOvenTemp > -300) {
            if (_SSRPID->Compute()) {
                getNewTemp = true;
                startSampleTime = millis();
#ifdef DEBUGIT                
                Serial.printf("OutputPower = %5.0f ms currentOvenTemp = %6.1f, goal = %6.1f\n\r", outputPower, currentOvenTemp, setPointTemp);
#endif                
            }
        
            now = millis();

            if ((now - pulseStartTime) > SSRPowerRange) {
                pulseStartTime += SSRPowerRange;
            }

            if ((now - pulseStartTime) < outputPower) {
                if (!SSRIsOn) {
                    digitalWrite(SSRPinUsed, HIGH);
                    SSRIsOn = true;
                }
            } else {
                if (SSRIsOn) {
                    digitalWrite(SSRPinUsed, LOW);
                    SSRIsOn = false;
                }
            }
        } else {
            if (tempFault) {
                // switch off SSR to prevent overheating
                if (SSRIsOn) {
                    digitalWrite(SSRPinUsed, LOW);
                    SSRIsOn = false;
                }
                allowPIDControllerIsOn = false;
            }
        }
    }
}

void PIDController::setControllerOn() {
    allowPIDControllerIsOn = true;
    pulseStartTime = millis();
}

void PIDController::setControllerOff() {
    allowPIDControllerIsOn = false;
    digitalWrite(SSRPinUsed, LOW);
    SSRIsOn = false;
}

void PIDController::setGoalOvenTemp(double NewOvenTemp, bool ignoreNegativeValue) {
    if ((NewOvenTemp < setPointTemp) && !ignoreNegativeValue) {
        _SSRPID->SetOutputLimits(0, 0.0001);
        _SSRPID->SetOutputLimits(0, (double) SSRPowerRange);
    }
    setPointTemp = NewOvenTemp;
    outputPower = 0;
}
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
